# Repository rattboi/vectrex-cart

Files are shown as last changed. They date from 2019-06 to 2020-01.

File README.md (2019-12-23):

VEXTREME Vectrex Multicart
===

We're carrying on and pushing forward the amazing work of [Sprite_tm](http://spritesmods.com/?art=veccart&page=1) and his Extreme Vectrex Multicart. He posted the code (GPLv3 License) and lots of screens of the PCB/initial schematic, but he never released the PCB. It's a great base for an inexpensive and open multicart, for developers and players alike!

3D Renders
===

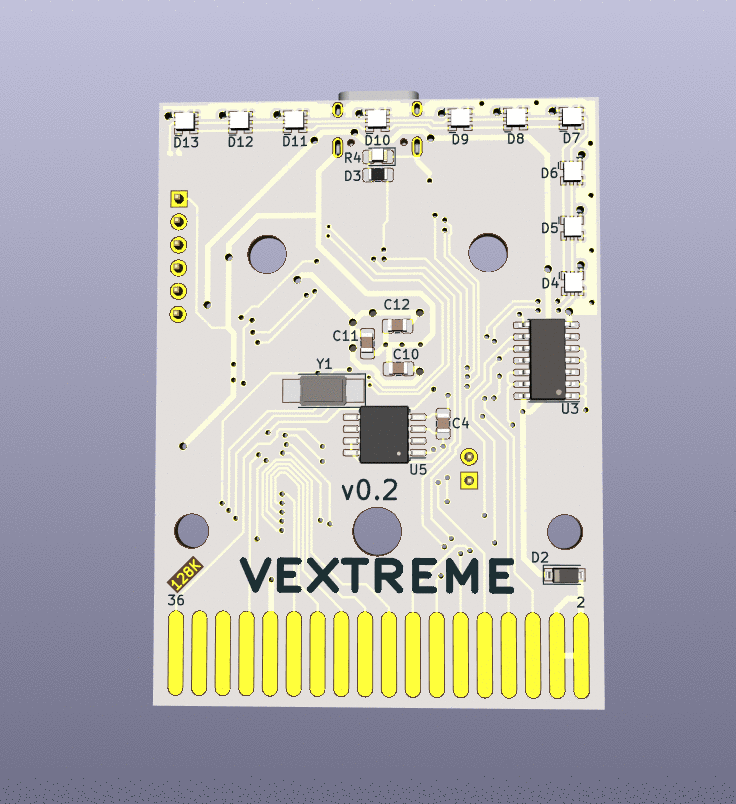
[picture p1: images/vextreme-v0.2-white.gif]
v0.2 Render


Video Updates
===

Be sure to subscribe to my Youtube channel for updates!  Here's my [Vectrex playlist](https://www.youtube.com/watch?v=zkJ-z77fJCw&list=PL7MgXfpGKg6CCaIQejZVb5CsTg3-5mHU0&index=1) if you want to stay laser focused on this project.

BOM and Parts ordering
===

All the parts are described in [veccart.csv](bom/veccart.csv)

Also, you can use this [Digi-Key shared cart](https://www.digikey.com/short/pv2qr0) if you're in a hurry.  It has will have part references right on the packages for you!

:pencil: Note: The USB-C connector I chose is not available at Digi-Key, check Google for "Korean Hroparts Elec TYPE-C-31-M-12".

Ordering PCB's
===

OSHPark is a good place to order with purple or the new "after dark" theme color scheme.  You can upload the KiCad [veccart.kicad_pcb](hardware/veccart.kicad_pcb) there directly.  I would download this entire Github repo ZIP file first though instead of just trying to save the PCB file from your browser.

Another way to order PCB's is by using the included [gerbers](hardware/gerbers) and uploading those with all of the necessary specs to companies like [PCBWay](https://www.pcbway.com) or [JLCPCB](https://jlcpcb.com)

Building and Flashing STM firmware
===

### This assumes you have these prerequisits installed:

- Docker
- dfu-util
- Make

### Build the stm32-build docker image
```
code/veccart $ make docker-build
```

### Connect the 2-pin jumper and then connect the cart to USB

### Check if your computer sees the STM32
```
$ dfu-util -l

dfu-util 0.9

Copyright 2005-2009 Weston Schmidt, Harald Welte and OpenMoko Inc.
Copyright 2010-2019 Tormod Volden and Stefan Schmidt
This program is Free Software and has ABSOLUTELY NO WARRANTY
Please report bugs to http://sourceforge.net/p/dfu-util/tickets/

Deducing device DFU version from functional descriptor length
Found DFU: [0483:df11] ver=2200, devnum=22, cfg=1, intf=0, path="20-1.4.3", alt=3, name="@Device Feature/0xFFFF0000/01*004 e", serial="123412341234"
Found DFU: [0483:df11] ver=2200, devnum=22, cfg=1, intf=0, path="20-1.4.3", alt=2, name="@OTP Memory /0x1FFF7800/01*512 e,01*016 e", serial="123412341234"
Found DFU: [0483:df11] ver=2200, devnum=22, cfg=1, intf=0, path="20-1.4.3", alt=1, name="@Option Bytes  /0x1FFFC000/01*016 e", serial="123412341234"
Found DFU: [0483:df11] ver=2200, devnum=22, cfg=1, intf=0, path="20-1.4.3", alt=0, name="@Internal Flash  /0x08000000/04*016Kg,01*064Kg,03*128Kg", serial="123412341234"
```

### Build and flash the STM32 image via dfu-util
```
code/veccart $ make clean all flash

// You should end up with something like this

Downloading to address = 0x08000000, size = 23536
Download    [=========================] 100%        23536 bytes
Download done.
File downloaded successfully
```

### Remove the cart from USB and remove the jumper (install it on one pin so you don't lose it)

Building and Flashing the multicart's menu
===

### Build the asm6809 docker image
```
code/multicart $ make docker-build
```

### Connect the cart to USB with the 2-pin jumper removed

- The first time you do this you will likely have to format the USB drive

  - Name: VEXTREME
  - Format: MS-DOS (FAT)
  - Scheme: Master Boot Record

- Be patient, it's slow!  Don't worry, copying binaries later will be fast!!

### Build and flash the multicart menu binary
```
// Mac OS
code/multicart $ make clean all && cp multicart.bin /Volumes/VEXTREME/

// optionally add this to the above command to unmount, after you figure out which drive it is
$ diskutil list
&& diskutil unmountDisk /dev/disk3

// Linux
code/multicart $ make copy

// You should end up with something like this, and the binary should have been copied to the root of your multicart drive

asm6809  -B -o multicart.bin multicart.asm
```

Adding Vectrex Game ROMs (Binaries)
===

- Create a directory on your multicart called `roms/`

- Add your first binaries there, may I suggest: [Beluga Dreams](https://8-bit-waves.itch.io/beluga-dreams) and [Vec-Man](http://eiti.fh-pforzheim.de/personen/johannsen/projektlabor/vectrex_2019/vectrex_game_vec_man.htm) ?

Docs
===

A nice collection of lessons learned will be [documented here.](docs/)

Hall of Fame
===

If you build one of these, be sure to send me a message with your build pics showing your working VEXTREME multicart!  Or better yet, check out the [hall of fame format here](hall-of-fame/) and submit a PR (please and thank you!)

LICENSE
===

GPLv3 - essentially you must keep this open, all changes must be disclosed and shared.  Full [LICENSE here](LICENSE) and [TL;DR summary here](https://tldrlegal.com/license/gnu-general-public-license-v3-(gpl-3))

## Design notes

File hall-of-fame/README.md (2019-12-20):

Hall of Fame
===

If you build one of these, be sure to send me a message with your build pics showing your working VEXTREME multicart!  Or better yet, check out the format above and submit a PR (please and thank you!) - limit pic width to 600px please.

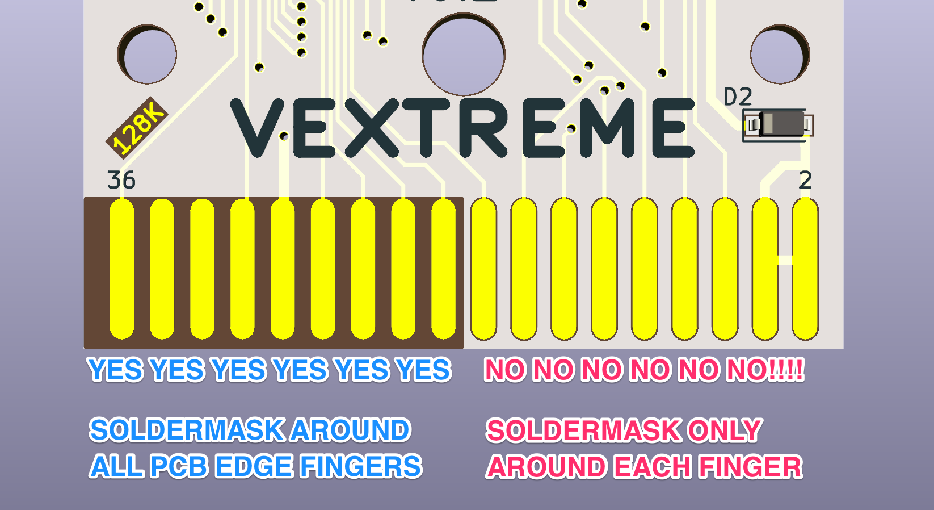
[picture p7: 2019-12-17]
docs/vectrex-cart-fingers.png

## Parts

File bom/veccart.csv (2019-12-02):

Ref | Qnty | Value | Cmp name | Footprint | Description | Vendor
C1, C2, C7, C6, | 4 | 2.2u | C | Capacitor_SMD:C_0805_2012Metric_Pad1.15x1.40mm_HandSolder | Unpolarized capacitor
C4, C3, C5, C10, C11, C12, | 6 | 100nF | C | Capacitor_SMD:C_0805_2012Metric_Pad1.15x1.40mm_HandSolder | Unpolarized capacitor
C8, C9, | 2 | 18pF | C | Capacitor_SMD:C_0805_2012Metric_Pad1.15x1.40mm_HandSolder | Unpolarized capacitor
C13, | 1 | 47u | C | Capacitor_SMD:C_0805_2012Metric_Pad1.15x1.40mm_HandSolder | Unpolarized capacitor
CON1, | 1 | vectrex-edge-connector | vectrex-edge-connector | veccart:vectrex-edge-connector-thinner
D1, D2, | 2 | MBR0520 | MBR0520 | Diode_SMD:D_SOD-123 | 20V 0.5A Schottky Power Rectifier Diode, SOD-123
D3, | 1 | LED | LED | LED_SMD:LED_0805_2012Metric_Pad1.15x1.40mm_HandSolder | Light emitting diode
D13, D12, D11, D10, D9, D8, D7, D6, D5, D4, | 10 | APA102-2020 | APA102-2020 | veccart:LED-APA102-2020_6 | RGB LED with integrated controller
J1, | 1 | USB_C_Receptacle_USB2.0 | USB_C_Receptacle_USB2.0 | veccart:USB_C_Receptacle_HRO_TYPE-C-31-M-12 | USB 2.0-only Type-C Receptacle connector
J2, | 1 | Conn_01x06_Male | Conn_01x06_Male | Connector_PinHeader_2.54mm:PinHeader_1x06_P2.54mm_Vertical | Generic connector, single row, 01x06, script generated (kicad-library-utils/schlib/autogen/connector/)
JP1, | 1 | Jumper_NO_Small | Jumper_NO_Small | Connector_PinHeader_2.54mm:PinHeader_1x02_P2.54mm_Vertical | Jumper, normally open, small symbol
R1, R2, | 2 | 22 | R | Resistor_SMD:R_0805_2012Metric_Pad1.15x1.40mm_HandSolder | Resistor
R3, | 1 | 10k | R | Resistor_SMD:R_0805_2012Metric_Pad1.15x1.40mm_HandSolder | Resistor
R4, | 1 | 220 | R | Resistor_SMD:R_0805_2012Metric_Pad1.15x1.40mm_HandSolder | Resistor
R5, R6, | 2 | 5.1k | R | Resistor_SMD:R_0805_2012Metric_Pad1.15x1.40mm_HandSolder | Resistor
U1, | 1 | LM1117-3.3 | LM1117-3.3 | Package_TO_SOT_SMD:SOT-223-3_TabPin2 | 800mA Low-Dropout Linear Regulator, 3.3V fixed output, TO-220/TO-252/TO-263/SOT-223
U2, | 1 | STM32F411RCTx | STM32F411RCTx | Package_QFP:LQFP-64_10x10mm_P0.5mm | ARM Cortex-M4 MCU, 256KB flash, 128KB RAM, 100MHz, 1.7-3.6V, 50 GPIO, LQFP-64
U3, | 1 | 74HC32 | 74LS32 | Package_SO:SOIC-14_3.9x8.7mm_P1.27mm | Quad 2-input OR
U4, | 1 | SN74LVC8T245DB | SN74LVC8T245DB | Package_SO:SSOP-24_5.3x8.2mm_P0.65mm | 8-bit dual supply translating transceiver, 3-state, SSOP-24
U5, | 1 | W25Q128 | W25Q128 | Package_SO:SOIC-8_5.23x5.23mm_P1.27mm | External EEPROM with SPI interface in 8-pin package
Y1, | 1 | 8MHz | Crystal | Crystal:Crystal_SMD_5032-2Pin_5.0x3.2mm_HandSoldering | Two pin crystal

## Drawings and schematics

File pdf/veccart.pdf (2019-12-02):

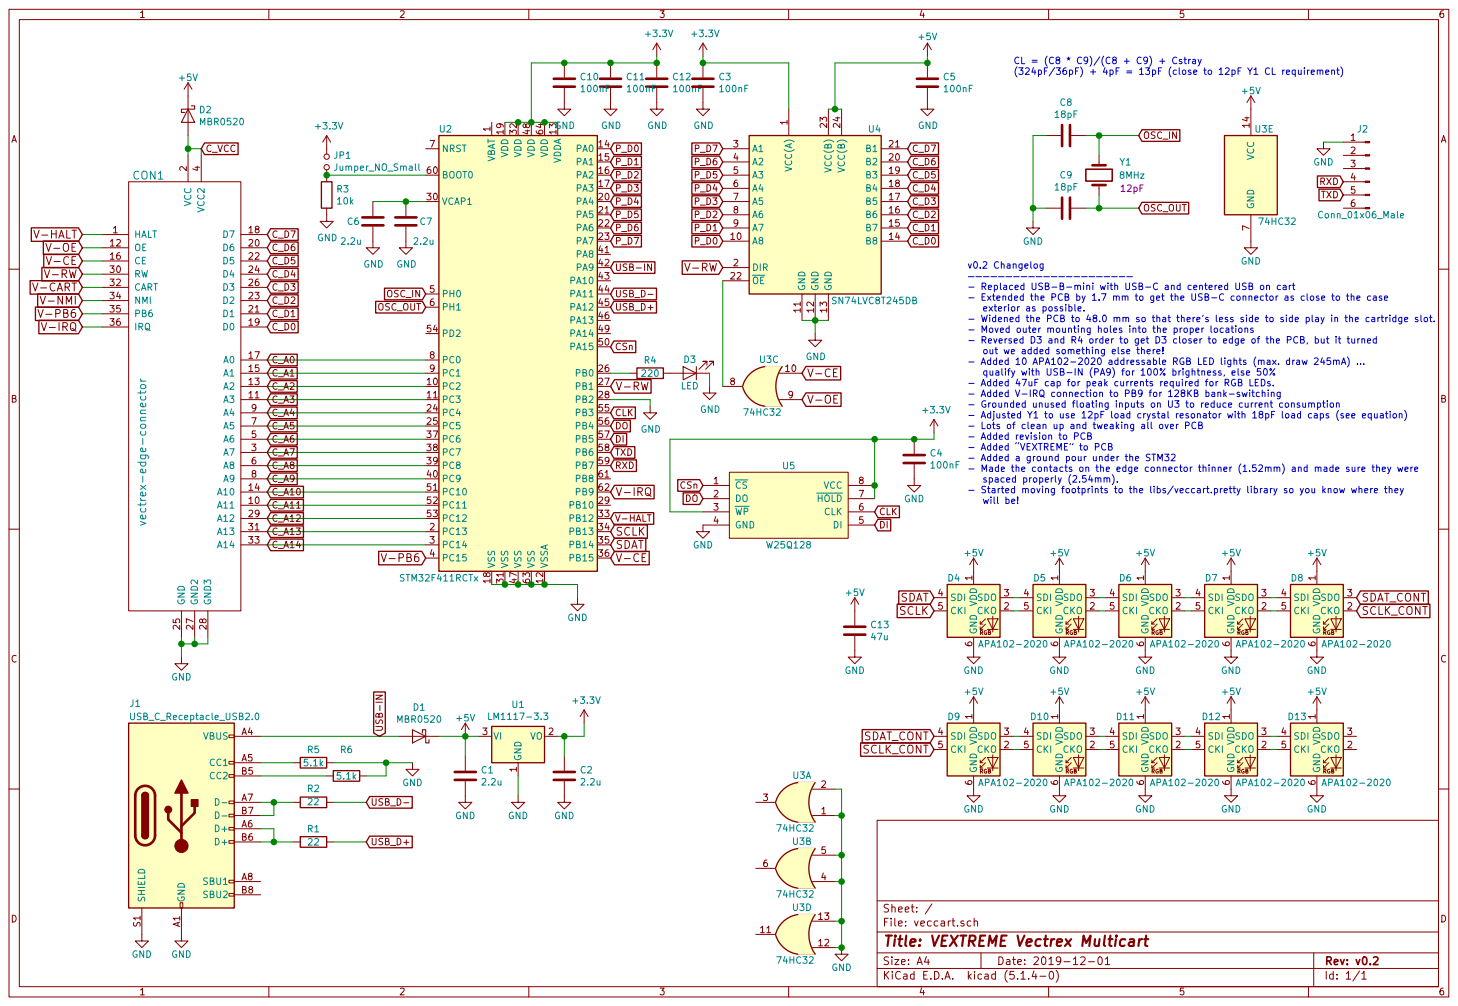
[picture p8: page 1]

1 VCAP1 30 VDD 19 VDD 32 VDD 48 VDD 64 VDDA 13 VSS 18 VSS 31 VSS 47 VSS 63 VSSA 12 U2 STM32F411RCTx VCC 14 GND

6 D13 APA102-2020 CS 1 DO 2 WP 3 GND 4 DI 5 CLK 6 HOLD 7 VCC 8 U5 W25Q128 VCC(A) 1 A8 10 GND 11 GND 12 GND 13 B8 14 B7 15 B6 16 B5 17 B4 18 B3 19 DIR 2 B2 20 B1 21 OE 22 VCC(B) 23 VCC(B) 24 A1 3 A2 4 A3 5 A4 6 A5 7 A6 8 A7 9 U4 SN74LVC8T245DB

2 D6 20 D1 21 D5 22 D2 23 D4 24 GND 25 D3 26 GND2 27 GND3 28 A12 29 A7 3 RW 30 A13 31 CART 32 A14 33 NMI 34 PB6 35

6 D4 APA102-2020 HALT 1 A11 10 A3 11 OE 12 A2 13 A10 14 A1 15 CE 16 A0 17 D7 18 D0 19 VCC

- Replaced USB-B-mini with USB-C and centered USB on cart
- Extended the PCB by 1.7 mm to get the USB-C connector as close to the case
exterior as possible.
- Widened the PCB to 48.0 mm so that theres less side to side play in the cartridge slot.
- Moved outer mounting holes into the proper locations
- Reversed D3 and R4 order to get D3 closer to edge of the PCB, but it turned
out we added something else there!
- Added 10 APA102-2020 addressable RGB LED lights (max. draw 245mA)
qualify with USB-IN (PA9) for 100% brightness, else 50%
- Added 47uF cap for peak currents required for RGB LEDs.
- Added V-IRQ connection to PB9 for 128KB bank-switching
- Grounded unused floating inputs on U3 to reduce current consumption
- Adjusted Y1 to use 12pF load crystal resonator with 18pF load caps (see equation)
- Lots of clean up and tweaking all over PCB
- Added revision to PCB
- Added VEXTREME to PCB
- Added a ground pour under the STM32
- Made the contacts on the edge connector thinner (1.52mm) and made sure they were
spaced properly (2.54mm).
- Started moving footprints to the libs/veccart.pretty library so you know where they
will be!

1 CKO 2 SDO 3 SDI 4 CKI 5 GND

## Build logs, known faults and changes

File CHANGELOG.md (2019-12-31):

# Changelog

## Hardware TODO

- Move v0.2's PCB fingers 18.0mm from the center of 3.5mm mounting holes, and 0.5mm from board edge, for slightly better engagement with the Vectrex cartrdige connector.
- Remove soldermask from PCB cart fingers on top and bottom of the board.
- R4 & D3 reference designators are swapped.
- Remove D4 - D6 and just have addressible LEDs on the edge of the board, space the 7 LEDs evenly.
- Move the debugging/serial port connector so it does not interfere with enclosure bosses.
- Move V-HALT and V-CE to different pins and fix SDAT and SCLK so they are on SPI2 for hardware control. V-CE might be optimized for MSB (seems like it is in romemu.S), so move to PA15 which bumps CSn to some other pin? CSn should likely be on SPI1_SS, but it might not matter (check).  PB01 is used in an optimized way as well though.
- Replace U3 with a single OR gate?
- Replacement for U4 which is more available at LCSC?
- Slightly increase the middle pads on addressible LEDs so they don't require touch up soldering
- Route all unused GPIO to a breakout header, for hacking!
- Add ESD protection to external connections
- Move headers to USB-C side and edge for easier access
- Make 2-pin jumper a right angle switch instead of a jumper?

## Software TODO

- Add hardware SPI2 support
- Add cartridge RAM support (specifically for Animaction $2000-$27FF, but possibly for others as well).  Any downside to letting the entire 64KB of emulated ROM to be considered as RAM and writable?
- Add hardware version support for pin definitions
- Add 128KB bankswitching (V-INT pin)
- Developer mode, allow the cart to stay plugged into a computer and appear as a RAMDISK
- Figure out why Polar Rescue crashes when the sub launches

## v0.2

- Replaced USB-B-mini with USB-C and centered USB on cart
- Extended the PCB by 1.7 mm to get the USB-C connector as close to the case exterior as possible.
- Widened the PCB to 48.0 mm so that there’s less side to side play in the cartridge slot.
- Moved outer mounting holes into the proper locations
- Reversed D3 and R4 order to get D3 closer to edge of the PCB, but it turned out we added something else there!
- Added 10 APA102-2020 addressable RGB LED lights (max. draw 245mA) … qualify with USB-IN (PA9) for 100% brightness, else 50%
- Added 47uF cap for peak currents required for RGB LEDs.
- Added V-IRQ connection to PB9 for 128KB bank-switching
- Grounded unused floating inputs on U3 to reduce current consumption
- Adjusted Y1 to use 12pF load crystal resonator with 18pF load caps (see equation)
- Lots of clean up and tweaking all over PCB
- Added revision to PCB
- Added “VEXTREME” to PCB
- Added a ground pour under the STM32
- Made the contacts on the edge connector thinner (1.52mm) and made sure they were spaced properly (2.54mm).
- Started moving footprints to the libs/veccart.pretty library so you know where they will be!
- Add basic folder support #1
- Ignore dotfiles generated by MacOS
- Add software driven addressible LED support
- improve USB write time for a single game by 3x (32KB in 1 second)
- adds 'clean' and 'all' rules for multicart build
- create 4KB of space for menu (currently about 2KB), and reserve 60KB for menu data.
- Added a mostly optimized 100 vector logo for VEXTREME
- Added a much improved version of Malban's 5 line font (everything except lowercase, don't use lower)
- Reduced menu to 4 items at a time
- Added a special intro jingle that's been stuck in my head (enjoy!)
- temp increase time to reset to allow Fortress of Narzod to play
- Extract menu code from main code and optimize menu code
- Add basic menu labels/function-per-button support #4
    - At the bottom of the menu 1 = (BACK), 2 = PAGE LEFT, 3 = PAGE RIGHT, 4 = SELECT
- Ignore lst files #5
- adds ISSUE_TEMPLATE.md and PULL_REQUEST_TEMPLATE.md for contributions from the community
- Update to latest (pinned) libopencm3 #6
- Fixed lastselectcart on wrong game after reset
- Fixed do not inc page if next one will be blank issue
- Converts logo from sync to smart list, thanks Malban!
    - Note: Had to replace NOP MACROs with JSR of approx equivalent value
    - Converted fcb hi(label),lo(label) into fdb label
    - Reduces cycle count by 8 - 10k!

## v0.1

- Mostly unchanged from Sprite_tm's original HW/SW design
- Mostly unchanged from Rattboi's original PCB design
- fixes error opening PCB with latest KiCaD
- add gerbers for easy PCB ordering at many places
- update README.md and add LICENSE
- fixes premature automatic reset delay on GCE Vectrex
- fixes menu builder missing filename in path
- pretty up the menu by removing the .BIN file extension, and other cleanup
- let's call it the VEXTREME cart, for now. (original name was EXTREME)

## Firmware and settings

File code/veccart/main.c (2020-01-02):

/*
 *  Copyright (C) 2015 Jeroen Domburg <jeroen at spritesmods.com>
 *
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
 * You should have received a copy of the GNU Lesser General Public License
 * along with this library.  If not, see <http://www.gnu.org/licenses/>.
 */

#include <libopencm3/stm32/rcc.h>
#include <libopencm3/stm32/syscfg.h>
#include <libopencm3/stm32/gpio.h>
#include <libopencm3/stm32/usart.h>
#include <libopencm3/cm3/systick.h>
#include <libopencm3/stm32/exti.h>
#include <libopencm3/cm3/nvic.h>
#include <libopencm3/stm32/pwr.h>
#include <libopencm3/stm32/flash.h>
#include <stdlib.h>
#include <string.h>

#include "led.h"
#include "delay.h"
#include "main.h"
#include "menu.h"
#include "msc.h"

//#include "rom.h"
#include "xprintf.h"
#include "fatfs/ff.h"


//Memory for the menu ROM and the running cartridge.
//We keep both in memory so we can quickly exchange them when a reset has been detected.
const int menuFileCount = 0xffe;         // fixed location in multicart.bin
const int menuIndex = 0xfff;             // fixed location in multicart.bin
const int menuFilePointers = 0x1000;     // 256 pointers to filenames
const int menuFileStrings  = 0x1200;     // big chunk of ram to store filename strings

char menuData[8*1024];
char *romData=menuData;
unsigned char parmRam[256];

char menuDir[_MAX_LFN + 1];

union cart_and_listing {
	char cartData[64*1024];
	dir_listing listing;
};

union cart_and_listing c_and_l;

/*
//Pinning:
A0-A14,SWCTL - PC0-PC15
D0-D7 - PA0-PA7
nWR - PB1
nCART - PB15
led - PB0
USBPWR - PA9
*/

#define SYSCFG_MEMRMP			MMIO32(SYSCFG_BASE + 0x00)


void uart_output_func(unsigned char c){
	uint32_t reg;
	do {
		reg = USART_SR(USART1);
	} while ((reg & USART_SR_TXE) == 0);
	USART_DR(USART1) = (uint16_t) c & 0xff;
}

//Asm function
extern void romemu(void);

//Load a ROM into cartridge memory
void loadRom(char *fn) {
	FIL f;
	FRESULT fr;
	UINT r=0;
	int n;
	if (romData==c_and_l.cartData)
		n=sizeof(c_and_l.cartData);
	else
		n=sizeof(menuData);
	fr=f_open(&f, fn, FA_READ);
	if (fr) {
		xprintf("Error opening file: %d\n", fr);
	} else {
		xprintf("Opened file: %s\n", fn);
	}
	f_read(&f, romData, 64*1024, &r);
	if (n>32*1024 && r<=32*1024) {
		//Duplicate bank to upper bank
		for (n=0; n<32*1024; n++) romData[n+32*1024]=romData[n];
	}
	xprintf("Read %d bytes of rom data.\n", r);
	f_close(&f);
}

//Stream data, for the Bad Apple demo
//Name of the file sucks and I'd like to make a rpc function that's a bit
//more universal... you should eg be able to pass through the name of the
//file you'd like to stream and the address and chunk size... but this is
//a start.
FIL streamFile;
int streamLoaded=0;

void loadStreamData(int addr, int len) {
	UINT r=0;
	if (!streamLoaded) {
		f_open(&streamFile, "vec.bin", FA_READ);
		streamLoaded=1;
	}
	f_read(&streamFile, &romData[addr], len, &r);
}

void doUpDir() {
  if (strcmp(menuDir, "/roms") != 0)
    doChangeDir("..");
}

void doChangeDir(char* dirname) {
	xprintf("Found directory: %s\n", dirname);
	if (strcmp(dirname,"..") == 0) {
		char* ptr = strrchr(menuDir,'/');
		if (ptr != NULL) {
			*ptr = '\0';
		}
	} else {
		xsprintf(menuDir, "%s/%s", menuDir, dirname);
	}

	romData=menuData;
	loadListing(menuDir, &c_and_l.listing, romData, menuFilePointers, menuFileStrings, menuFileCount);
	menuData[menuIndex]=0; //reset selection

	xprintf("Done listing for : %s\n", menuDir);
}

//User has made a selection in the cart menu (chose the i'th item) so now we have to load the cartridge.
void doChangeRom(char* basedir, int i) {
	char buff[300];

	menuData[menuIndex]=i; //save selection so we can go back there after reset
	xprintf("Changing to rom no %d in %s\n", i, basedir);
	sortDirectory(basedir, &c_and_l.listing); // recreate file listing, as loading a cart overwrote the union
	file_entry f = c_and_l.listing.f_entry[i];

	if (f.is_dir) {
		doChangeDir(f.fname);
	} else {													/* It is a file. */
		xprintf("Adding filename [%s] to path\n", f.fname);
		xsprintf(buff, "%s/%s", basedir, f.fname);

		romData=c_and_l.cartData;
		xprintf("Going to read rom image %s\n", buff);
		loadRom(buff);
	}
}

//Handle an RPC event
void doHandleEvent(int data) {
	// xprintf("Event: %d. arg1: 0x%x\n", data, (int)parmRam[254]);
	if (data==1) doChangeRom(menuDir, (int)parmRam[254]);
	if (data==2) loadStreamData(0x4000, 1024+512);
	if (data==3) doUpDir();
	// xprintf("Event handled. Resuming.\n");
}

void doDbgHook(int adr, int data) {
	xprintf("R %x %x\n", adr, data);
}

static FATFS FatFs;

int main(void) {
	void (*runptr)(void)=romemu;

  const struct rcc_clock_scale hse_8mhz_3v3_120MHz = { /* 120MHz */
     .pllm = 8,
     .plln = 240,
     .pllp = 2,
     .pllq = 5,
     .pllr = 0,
     .pll_source = RCC_CFGR_PLLSRC_HSE_CLK,
     .hpre = RCC_CFGR_HPRE_DIV_NONE,
     .ppre1 = RCC_CFGR_PPRE_DIV_4,
     .ppre2 = RCC_CFGR_PPRE_DIV_2,
     .voltage_scale = PWR_SCALE1,
     .flash_config = FLASH_ACR_ICEN | FLASH_ACR_DCEN | FLASH_ACR_LATENCY_3WS,
     .ahb_frequency  = 120000000,
     .apb1_frequency = 30000000,
     .apb2_frequency = 60000000,
  };

	rcc_clock_setup_pll(&hse_8mhz_3v3_120MHz);
	rcc_periph_clock_enable(RCC_GPIOA);
	rcc_periph_clock_enable(RCC_GPIOB);
	rcc_periph_clock_enable(RCC_GPIOC);
	rcc_periph_clock_enable(RCC_USART1);
	rcc_periph_clock_enable(RCC_SYSCFG);

	//Addressable LEDs - output
	gpio_mode_setup(GPIOB, GPIO_MODE_OUTPUT, GPIO_PUPD_NONE, GPIO13 | GPIO14);
	// gpio_set_output_options(GPIOB, GPIO_OTYPE_PP, GPIO_OSPEED_2MHZ,  GPIO13 | GPIO14);
	//LED - output
	gpio_mode_setup(GPIOB, GPIO_MODE_OUTPUT, GPIO_PUPD_NONE, GPIO0);
	//USB power - input
	gpio_mode_setup(GPIOA, GPIO_MODE_INPUT, GPIO_PUPD_PULLDOWN, GPIO9);

	//PB6/PB7: txd/rxd
	gpio_mode_setup(GPIOB, GPIO_MODE_AF, GPIO_PUPD_NONE, GPIO6 | GPIO7);
	gpio_set_af(GPIOB, GPIO_AF7, GPIO6 | GPIO7);

	usart_set_baudrate(USART1, 115200);
	usart_set_databits(USART1, 8);
	usart_set_stopbits(USART1, USART_STOPBITS_1);
	usart_set_mode(USART1, USART_MODE_TX);
	usart_set_parity(USART1, USART_PARITY_NONE);
	usart_set_flow_control(USART1, USART_FLOWCONTROL_NONE);
	/* Finally enable the USART. */
	usart_enable(USART1);
	xdev_out(uart_output_func);

	//Address lines - input (A0 - A14 & PB6)
	gpio_mode_setup(GPIOC, GPIO_MODE_INPUT, GPIO_PUPD_PULLDOWN,
		GPIO0|GPIO1|GPIO2|GPIO3|GPIO4|GPIO5|GPIO6|GPIO7|GPIO8|GPIO9|GPIO10|GPIO11|GPIO12|GPIO13|GPIO14|GPIO15);
	// gpio_mode_setup(GPIOB, GPIO_MODE_INPUT, GPIO_PUPD_NONE,
	// 	GPIO13|GPIO14);
	// IRQ
	gpio_mode_setup(GPIOB, GPIO_MODE_INPUT, GPIO_PUPD_NONE, GPIO9);

	//Data lines - output
	gpio_mode_setup(GPIOA, GPIO_MODE_OUTPUT, GPIO_PUPD_NONE,
		GPIO0|GPIO1|GPIO2|GPIO3|GPIO4|GPIO5|GPIO6|GPIO7);

	//Control lines - input
	gpio_mode_setup(GPIOB, GPIO_MODE_INPUT, GPIO_PUPD_NONE,
		GPIO1|GPIO15);

	// SysTick setup (calls sys_tick_handler() every 1ms), also required for delay/millis
	systick_set_reload(120000);
	systick_set_clocksource(STK_CSR_CLKSOURCE_AHB);
	systick_counter_enable();
	systick_interrupt_enable();

	xprintf("Inited.\n");

	// Test Addressable LEDs
	// Addressable RGB LEDs
	uint32_t colors[] = {
		0,		  // off
		0xFF0000, // red
		0xFF9900, // orange
		0xFFFF00, // yellow
		0x00FF00, // green
		0x00FFFF, // cyan
		0x0000FF, // blue
		0x7700FF, // pink
		0xFF00FF, // magenta
		0xFFFFFF  // white
	};
	ledsInitSW(10, GPIOB, GPIO14, GPIOB, GPIO13, RGB_BGR);
	ledsSetBrightness(150); // be careful not to set this too high when using white, those LEDs draw some power!!
	uint32_t start = millis();
	while (millis() - start <= 2000UL) {
		rainbowCycle(10);
	}

#if 0 // TEST LED CODE START
	while (1) {
		// color wipe back and fourth through the list of colors
		ledsClear();
		ledsSetBrightness(150);
		bool dir = true;
		for (int x = 1; x < sizeof(colors)/sizeof(*colors); x++) {
			colorWipe(dir, colors[x], 50);
			dir = !dir;
		}

		ledsClear();
		ledsSetBrightness(255);
		rainbowCycle(10);
		rainbowCycle(10);

		ledsClear();
		knightRider(6, 64, 4, 2, 8, 0xFF7700); // Cycles, Speed, Width, First, Last, RGB Color (original orange-red)
		knightRider(3, 32, 4, 2, 8, 0xFF00FF); // Cycles, Speed, Width, First, Last, RGB Color (purple)
		knightRider(3, 32, 4, 2, 8, 0x0000FF); // Cycles, Speed, Width, First, Last, RGB Color (blue)
		knightRider(3, 32, 5, 2, 8, 0x00FF00); // Cycles, Speed, Width, First, Last, RGB Color (green)
		knightRider(3, 32, 5, 2, 8, 0xFFFF00); // Cycles, Speed, Width, First, Last, RGB Color (yellow)
		knightRider(3, 32, 7, 2, 8, 0x00FFFF); // Cycles, Speed, Width, First, Last, RGB Color (cyan)
		knightRider(3, 32, 7, 2, 8, 0xFFFFFF); // Cycles, Speed, Width, First, Last, RGB Color (white)

		// Iterate through a whole rainbow of colors
		for(uint8_t j=0; j<252; j+=7) {
			knightRider(1, 16, 2, 0, 8, colorWheel(j)); // Cycles, Speed, Width, RGB Color
		}

		ledsClear();
		ledsSetBrightness(255);
		int y = 10;
		for (int x=0; x<10; x++) {
			theaterChaseRainbow(y);
			y += 5;
		}
	}
#endif // TEST LED CODE END

	//If USB power pin is high, boot into USB disk mode
	if (gpio_get(GPIOA, GPIO9)) {
		xprintf("USB dev mode.\n");
		ramdiskmain();
	} else {
		// disable this or it will delay our ROM emulation!
		systick_interrupt_disable();

		//Load the menu game
		strncpy(menuDir, "/roms", sizeof(menuDir));
		f_mount(&FatFs, "", 0);
		loadRom("/multicart.bin");
		loadListing(menuDir, &c_and_l.listing, romData, menuFilePointers, menuFileStrings, menuFileCount);

		//Go emulate a ROM.
		SYSCFG_MEMRMP=0x3; //mak ram at 0
		runptr=(char*)(((int)runptr&0x1ffff)|1); //map to lower mem
		xprintf("Gonna start romemu at %08x\n", romemu);
		runptr();
	}

	return 0;
}

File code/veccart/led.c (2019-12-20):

#include <stdlib.h>

#include <libopencm3/stm32/rcc.h>
#include <libopencm3/stm32/gpio.h>
#include <libopencm3/stm32/spi.h>
#include "xprintf.h"
#include "delay.h"

// APA102-2020 Driver - SPI2 Hardware
// CS   - 33 - PB12  - SPI2_NSS  - NA v0.2 HW (currently V-HALT)
// SCLK - 34 - PB13  - SPI2_SCK  - As of v0.2 HW (use SW SPI)
// SDAT - 35 - PB14  - SPI2_MISO - As of v0.2 HW (use SW SPI)
// DO   - 36 - PB15  - SPI2_MOSI - NA v0.2 HW (currently V-CE)

/*------------------------------------------------------------------------
  Ported to STM32F411 for VEXTREME by Technobly

  ------------------------------------------------------------------------
  -- original header follows ---------------------------------------------
  ------------------------------------------------------------------------

  Arduino library to control Adafruit Dot Star addressable RGB LEDs.

  Written by Limor Fried and Phil Burgess for Adafruit Industries.

  Adafruit invests time and resources providing this open source code,
  please support Adafruit and open-source hardware by purchasing products
  from Adafruit!

  ------------------------------------------------------------------------
  This file is part of the Adafruit Dot Star library.

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
  You should have received a copy of the GNU Lesser General Public
  License along with NeoPixel.  If not, see <http://www.gnu.org/licenses/>.
  ------------------------------------------------------------------------*/

#include "led.h"
#include <string.h>

#define USE_HW_SPI 255 // Assign this to dataPin to indicate 'hard' SPI

uint16_t numLEDs;                // Number of pixels
uint16_t dataPin;                // If soft SPI, data pin #
uint32_t dataPort;               // If soft SPI, data pin port #
uint16_t clockPin;               // If soft SPI, clock pin #
uint32_t clockPort;              // If soft SPI, clock pin port #
uint8_t brightness;              // Global brightness setting
uint8_t *pixels;                 // LED RGB values (3 bytes ea.)
uint8_t rOffset;                 // Index of red in 3-byte pixel
uint8_t gOffset;                 // Index of green byte
uint8_t bOffset;                 // Index of blue byte

void leds_hw_spi_init(void);     // Start hardware SPI
void leds_hw_spi_end(void);      // Stop hardware SPI
void leds_sw_spi_init(void);     // Start bitbang SPI
void leds_sw_spi_out(uint8_t n); // Bitbang SPI write
void leds_sw_spi_end(void);      // Stop bitbang SPI




//--------------- FUN ROUTINES START --------------

// Input a value 0 to 255 to get a color value.
// The colours are a transition r - g - b - back to r.
uint32_t Wheel(uint8_t WheelPos) {
    if (WheelPos < 85) {
        return ledsColor(WheelPos * 3, 255 - WheelPos * 3, 0);
    } else if (WheelPos < 170) {
        WheelPos -= 85;
        return ledsColor(255 - WheelPos * 3, 0, WheelPos * 3);
    } else {
        WheelPos -= 170;
        return ledsColor(0, WheelPos * 3, 255 - WheelPos * 3);
    }
}

// Cycle through the color Wheel one complete revolution on all LEDs
void rainbow(uint8_t wait) {
    uint16_t i, j;
    for (j=0; j<256; j++) {
        for (i=0; i<ledsNumPixels(); i++) {
            ledsSetPixelColor(i, Wheel((i+j) & 255));
        }
        ledsUpdate();
        delay(wait);
    }
}

// Slightly different, this makes the rainbow equally distributed throughout, then wait (ms)
void rainbowCycle(uint8_t wait) {
    uint16_t i, j;
    for (j = 0; j < 256; j++) { // 1 cycle of all colors on wheel
        for (i = 0; i < ledsNumPixels(); i++) {
            ledsSetPixelColor(i, Wheel(((i * 256 / ledsNumPixels()) + j) & 255));
        }
        ledsUpdate();
        delay(wait);
    }
}

// Wipe a color across all LEDs with a particular direction and speed/delay
void colorWipe(bool dir, uint32_t c, uint8_t wait) {
    int i;
    if (dir) {
        for (i = 0; i < ledsNumPixels(); i++) {
            ledsSetPixelColor(i, c);
            ledsUpdate();
            delay(wait);
        }
    } else {
        for (i = ledsNumPixels() - 1; i >= 0; i--) {
            ledsSetPixelColor(i, c);
            ledsUpdate();
            delay(wait);
        }
    }
}

uint32_t dimColor(uint32_t color, uint8_t width) {
   return (((color&0xFF0000)/width)&0xFF0000) + (((color&0x00FF00)/width)&0x00FF00) + (((color&0x0000FF)/width)&0x0000FF);
}

// Using a counter and for() loop, input a value 0 to 251 to get a color value.
// The colors transition like: red - org - ylw - grn - cyn - blue - vio - mag - back to red.
// Entering 255 will give you white, if you need it.
uint32_t colorWheel(uint8_t WheelPos) {
  uint8_t state = WheelPos / 21;
  switch(state) {
    case 0: return ledsColor(255, 0, 255 - ((((WheelPos % 21) + 1) * 6) + 127)); break;
    case 1: return ledsColor(255, ((WheelPos % 21) + 1) * 6, 0); break;
    case 2: return ledsColor(255, (((WheelPos % 21) + 1) * 6) + 127, 0); break;
    case 3: return ledsColor(255 - (((WheelPos % 21) + 1) * 6), 255, 0); break;
    case 4: return ledsColor(255 - (((WheelPos % 21) + 1) * 6) + 127, 255, 0); break;
    case 5: return ledsColor(0, 255, ((WheelPos % 21) + 1) * 6); break;
    case 6: return ledsColor(0, 255, (((WheelPos % 21) + 1) * 6) + 127); break;
    case 7: return ledsColor(0, 255 - (((WheelPos % 21) + 1) * 6), 255); break;
    case 8: return ledsColor(0, 255 - ((((WheelPos % 21) + 1) * 6) + 127), 255); break;
    case 9: return ledsColor(((WheelPos % 21) + 1) * 6, 0, 255); break;
    case 10: return ledsColor((((WheelPos % 21) + 1) * 6) + 127, 0, 255); break;
    case 11: return ledsColor(255, 0, 255 - (((WheelPos % 21) + 1) * 6)); break;
    default: return ledsColor(0, 0, 0); break;
  }
}
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

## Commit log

2017-12-16 initial version
    [bloxorz.kicad_pcb, bloxorz.sch]
2017-12-27 PCB rev 3
    [bloxorz.kicad_pcb, bloxorz.sch]
2018-01-07 rev 4
    [bloxorz.kicad_pcb, bloxorz.sch]
2019-05-30 Removing bloxorz-related stuff, naming to generic cart name
    [veccart.kicad_pcb, veccart.sch]
2019-06-10 Found basic symbols/footprints. Added base code as well
    [veccart-2019-06-10-11-20-32.sch, veccart.kicad_pcb, veccart.sch]
2019-06-11 Add the rest of the footprints. Needs placed and routed
    [veccart.kicad_pcb, veccart.sch]
2019-06-11 Added a few missing values, got all passives on pcb
    [veccart.kicad_pcb, veccart.sch]
2019-06-11 Found a few small schematic misses. Started routing.
    [veccart.kicad_pcb, veccart.sch]
2019-06-12 More sch/pcb work
    SCH: labeled the rest of the cart lines to make the nets have nice names
    SCH: labeled rxd/txd pins used for usart1 (used for debugging), even
    though apparently they aren't routed on the board...?
    PCB: more power routing
    [veccart.kicad_pcb, veccart.sch]
2019-06-17 More board routing
    [veccart.kicad_pcb]
2019-06-18 Lots more routing, fixed some schematic mishaps
    [veccart.kicad_pcb, veccart.sch]
2019-06-18 Little more routing/cleanup
    [veccart.kicad_pcb]
2019-06-18 Crystal is more realistic fp, routed last bits!
    [veccart.kicad_pcb, veccart.sch]
2019-06-19 Added more datasheets for parts (towards BOM)
    [veccart.sch]
2019-06-19 More routing optimizations
    [veccart.kicad_pcb]
2019-06-19 Added debug uart, fixed 3d holes, renders
    [veccart.kicad_pcb, veccart.sch]
2019-06-20 Added basic BOM
    Change usb to digikey-modeled part
    Update schematic/layout to fit new usb
    Fix digikey part to fit pin naming in schematic for shield
    [veccart.csv, veccart.kicad_pcb, veccart.sch]
2019-06-20 Make BOM parseable csv
    [veccart.csv]
2019-06-20 Add 3d model for crystal oscillator (all parts are 3d now)
    [veccart.kicad_pcb]
2019-06-20 Add BOM link on readme, small layout optimizations
    [veccart.kicad_pcb]
2019-06-20 Updated 3d renders w/ new 3d footprints
2019-06-20 Add link to BOM from readme
2019-06-21 Added silkscreen graphics/text and new render
    [veccart.kicad_pcb]
2019-11-27 fixes error opening PCB with latest KiCaD
    [veccart.kicad_pcb]
2019-11-27 add gerbers for easy PCB ordering at many places
    [veccart-B_Cu.gbl, veccart-B_Mask.gbs, veccart-B_Paste.gbp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]
2019-11-27 fixes menu builder missing filename in path
    [main.c]
2019-12-02 v0.2 updates, see CHANGELOG.md
    [veccart-2019-06-10-11-20-32.sch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]
2019-12-02 Fixes BOM, and add new Digi-key shared cart
    [veccart.csv]
2019-12-17 Add folder support
    * Reset cursor to idx 0/pg 0 when entering/exiting directory
    * Proper path-building w/ '..', hide '..' at root rom dir
    * Remove extensions (.vec,.VEC,.bin,.BIN)
    * Sorted files/directories
    * Modify menu rom to self-identify in order to support directories
    Haven't found any bugs yet, and been playing with it for a while.
    Since we're sorting the directory and keeping it in-memory, I suppose
    there's a limit for the number of files per directory. This was imposed
    before via the amount of menu "cart" space that was dedicated to showing
    the listings anyways though.
    In order to not overuse memory, I've overlaid the directory structure w/
    the cartRam space, as their use is mutua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
    [main.c]
2019-12-20 Add software driven addressible LED support
2019-12-20 update hall-of-fame
2019-12-20 fixes slow USB operation
    [msc.c]
2019-12-23 create 4KB of space for menu (currently about 2KB), and reserve 60KB for menu data... jeez how many Vectrex ROMs do can haz?
2019-12-23 spiced up the cart with logo, fast fonts and tune :musical_note:
    - Added a mostly optimized 100 vector logo for VEXTREME
    - Added a much improved version of Malban's 5 line font (everything except lowercase, don't use lower)
    - Reduced menu to 4 items at a time
    - Added a special intro jingle that's been stuck in my head (enjoy!)
    - Cycle count currently at 28k, woot!
    - Moved pointer for start of menu data to 4Ki mark
2019-12-23 temp increase time to reset to allow Fortress of Narzod to play
    Fortress of Narzod has a really long intro song, so the shorter delay was timing out and resetting the game while it was playing the intro music. Need a better more direct sure fire heuristic for the reset button to force games back to the VEXTREME menu.
2019-12-24 Small, random menu fixes
    1) Got the better, smaller rpc header check routine to work
    2) Jump to loop instead of main, now that there's the logo
    3) Replace magic constants for menu item length w/ define
    [main.c]
2019-12-24 Extract menu code from main code
    First pass at removing the generic menu code from the device-specific
    main code. There's clearly still lots of room for improvement, but it's
    still functional and headed in the right way, imo.
2019-12-27 Add basic menu labels/function-per-button support (needs work)
    1 = up dir
    2 = page left
    3 = page right
    4 = load rom/choose dir
2019-12-31 Update Hall-of-Fame #5
2020-01-02 Menu fixes to not allow selecting blank files
    [main.c]

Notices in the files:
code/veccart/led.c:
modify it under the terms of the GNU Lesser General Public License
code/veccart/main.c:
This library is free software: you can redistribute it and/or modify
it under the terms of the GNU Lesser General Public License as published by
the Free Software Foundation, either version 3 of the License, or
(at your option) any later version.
